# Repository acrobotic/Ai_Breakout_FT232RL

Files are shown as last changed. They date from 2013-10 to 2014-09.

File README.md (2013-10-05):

Overview
---
This repository includes the Eagle design files (schematics and layout) for our [FT232RL Brekout Board][1]. The FT232RL is a 
popular Integrated Circuit (IC) that provides a single-chip USB to asynchronous serial data (UART) transfer interface. This IC is
commonly known as the **FTDI chip** as it's manufactured by Future Technology Devices Internationa (FTDI).  

The FT232RL is extremely useful for sending data back and forth between a PC and a microcontroller (such as the ATMega328p 
that's used in the Arduino Uno R3). It can even be used to program a microcontroller whose boot section has been pre-loaded
with a bootloader (e.g., Optiboot).

For more info on how to use the FTDI and its use for data communication and microcontroller programming, please visit:
[http://learn.acrobotic.com/FTDI][2]

Product page
---
Please consider buying products from Acrobotic to help fund future Open-Source projects like this! We'll always put our best effort in every project, and release all our design files and code for you to use.

[Tutorials, technical details, and more information about this product can be found here: http://acrobotic.com/catalog/product/view/id/31][1]

License Information
---

All contents of this repository are licensed under a [Creative Commons Attribution-ShareAlike 3.0 Unported License](http://creativecommons.org/licenses/by-sa/3.0/).



[1]: http://acrobotic.com/catalog/product/view/id/31 "FT232RL Breakout Board"
[2]: http://learn.acrobotic.com/FTDI "Acrobotic FTDI Tutorial"

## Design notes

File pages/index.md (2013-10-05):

---
layout: page
title: Ai Breakout FT232RL
tagline: Board design files and example firmware for an FT232RL (FTDI) breakout board.
github_project: Ai_Breakout_FT232RL
github_user_url: https://github.com/acrobotic
---
{% include JB/setup %}
{% include INCLUDE.md %}

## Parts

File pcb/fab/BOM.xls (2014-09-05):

Ai Breakout FT232RL – BOM
Cisco Zabala (x1sc0@acrobotic.com) last updated: 05.09.2014
Manufacturer | Manuf. Part Number | Vendor | Vendor Part Number | Type | Designator | Qty | Description | Case | SMD, BGA, LCC, OR TH | Notes
Stackpole Electronics Inc | RMCF0603JT300R | Digi-Key | RMCF0603JT300RCT-ND | Resistors | R1 | 1 | RES 300 OHM 1/10W 5% 0603 | 0603 | SMD
Stackpole Electronics Inc | RMCF0603JT1K00 | Digi-Key | RMCF0603JT1K00CT-ND |  | R2 | 1 | RES 1K OHM 1/10W 5% 0603 | 0603 | SMD
Yageo | CC0603ZRY5V9BB104 | Digi-Key | 311-1343-1-ND | Capacitors | C1, C2 | 2 | CAP CER 0.1UF 50V Y5V 0603 | 0603 | SMD
Kemet | T491A106K010AT7280 | Digi-Key | 399-8268-1-ND |  | C3 | 1 | CAP TANT 10UF 10V 10% 1206 | EIA3216 | SMD
Yageo | CC0603ZRY5V7BB105 | Digi-Key | 311-1372-1-ND |  | C4 | 1 | CAP CER 1UF 16V Y5V 0603 | 0603 | SMD
OSRAM | LB Q39E-N1P1-35-1 | Digi-Key | 475-2815-1-ND | LEDs | ON | 1 | LED CHIPLED BLUE 470NM 0603 SMD | 0603 | SMD
OSRAM | LY Q976-P1S2-36 | Digi-Key | 475-2558-1-ND | IC | TXLED, RXLED | 2 | LED CHIPLED 587NM YLW 0603 SMD | 0603 | SMD
FTDI | FT232RL-REEL | Digi-Key | 768-1007-1-ND | ICs | IC1 | 1 | IC USB FS SERIAL UART 28-SSOP | 28-SSOP | SMD
 |  | Acrobotic | CON-00006 | Connectors | J1 | 1 | 0.1” Pitch, 6-Pin (Female, R/A) |  | TH
 |  | Acrobotic | CON-00002 | Connect. | JP1 | 1 | 0.1” Pitch, 8-Pin (Male) |  | TH | Easily cut to length
 |  | Acrobotic | CON-00014 |  | USB | 1 | CONN USB MICRO B RECPT SMT R/A |  | SMD
 |  | Acrobotic | CON-00008 | Connect. | - | 1 | 2-Pin Jumper |  | - | For power selection

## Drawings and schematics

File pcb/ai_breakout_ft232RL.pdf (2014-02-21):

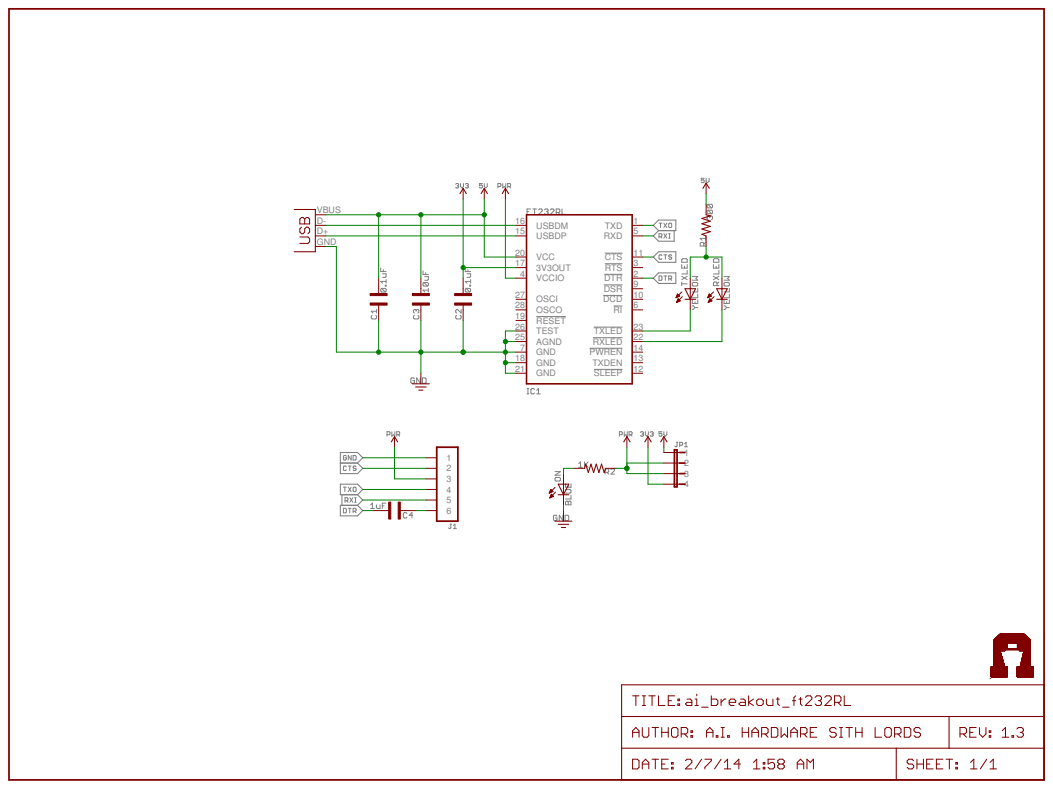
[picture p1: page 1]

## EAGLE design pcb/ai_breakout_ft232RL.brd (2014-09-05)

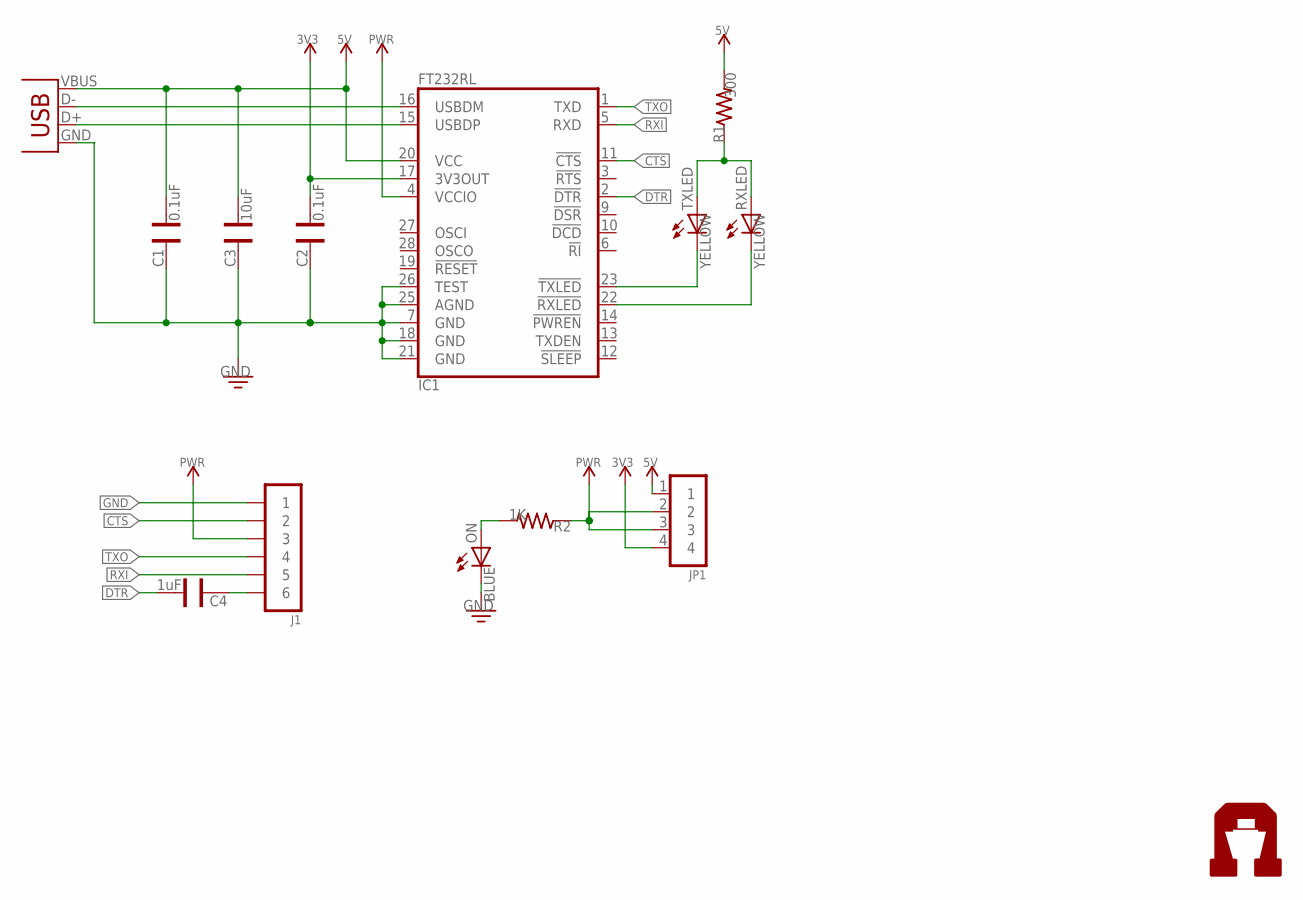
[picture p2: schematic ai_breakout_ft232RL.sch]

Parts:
C1, C2: 0.1uF; CAP-0603
C3: 10uF; CAP-0603
C4: 1uF; CAP-0603
IC1: FT2332RL; SSOP28-LD
J1: 1X06LONG; 1X06-LONG
JP1: 1X04NOSILK; 1X04-NOSILK
ON: BLUE; LED-0603
R1: 300; RES-0603
R2: 1K; RES-0603
RXLED: YELLOW; LED-0603
TXLED: YELLOW; LED-0603
U$3: AI-LOGOL; AI-LOGO-L
USB1: USBMICROB-TH; USB-MICROB-TH

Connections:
3V3: C2.1, IC1.17 (3V3OUT), JP1.4
5V: C1.1, C3.1, IC1.20 (VCC), JP1.1, R1.2, USB1.VBUS
CTS: IC1.11 (!CTS), J1.2
DTR: C4.1, IC1.2 (!DTR)
GND: C1.2, C2.2, C3.2, IC1.7 (GND), IC1.18 (GND), IC1.21 (GND), IC1.25 (AGND), IC1.26 (TEST), J1.1, ON.C, USB1.GND
unnamed: IC1.23 (!TXLED), TXLED.C
unnamed: IC1.22 (!RXLED), RXLED.C
unnamed: IC1.16 (USBDM), USB1.D-
unnamed: IC1.15 (USBDP), USB1.D+
unnamed: ON.A, R2.2
unnamed: R1.1, RXLED.A, TXLED.A
unnamed: C4.2, J1.6
PWR: IC1.4 (VCCIO), J1.3, JP1.2, JP1.3, R2.1
RXI: IC1.5 (RXD), J1.5
TXO: IC1.1 (TXD), J1.4

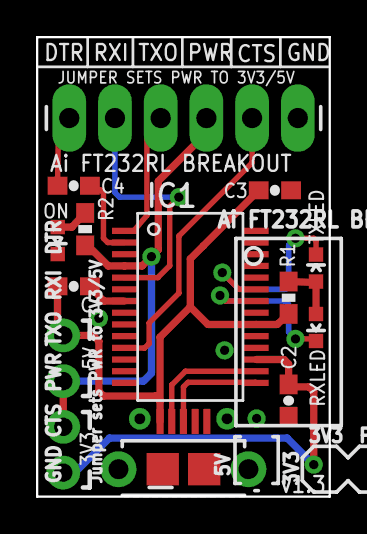
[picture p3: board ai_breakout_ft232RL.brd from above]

Board: 2 copper layers, 16.3 x 25.5 mm, 14 parts (1 on the bottom side), 15 nets.

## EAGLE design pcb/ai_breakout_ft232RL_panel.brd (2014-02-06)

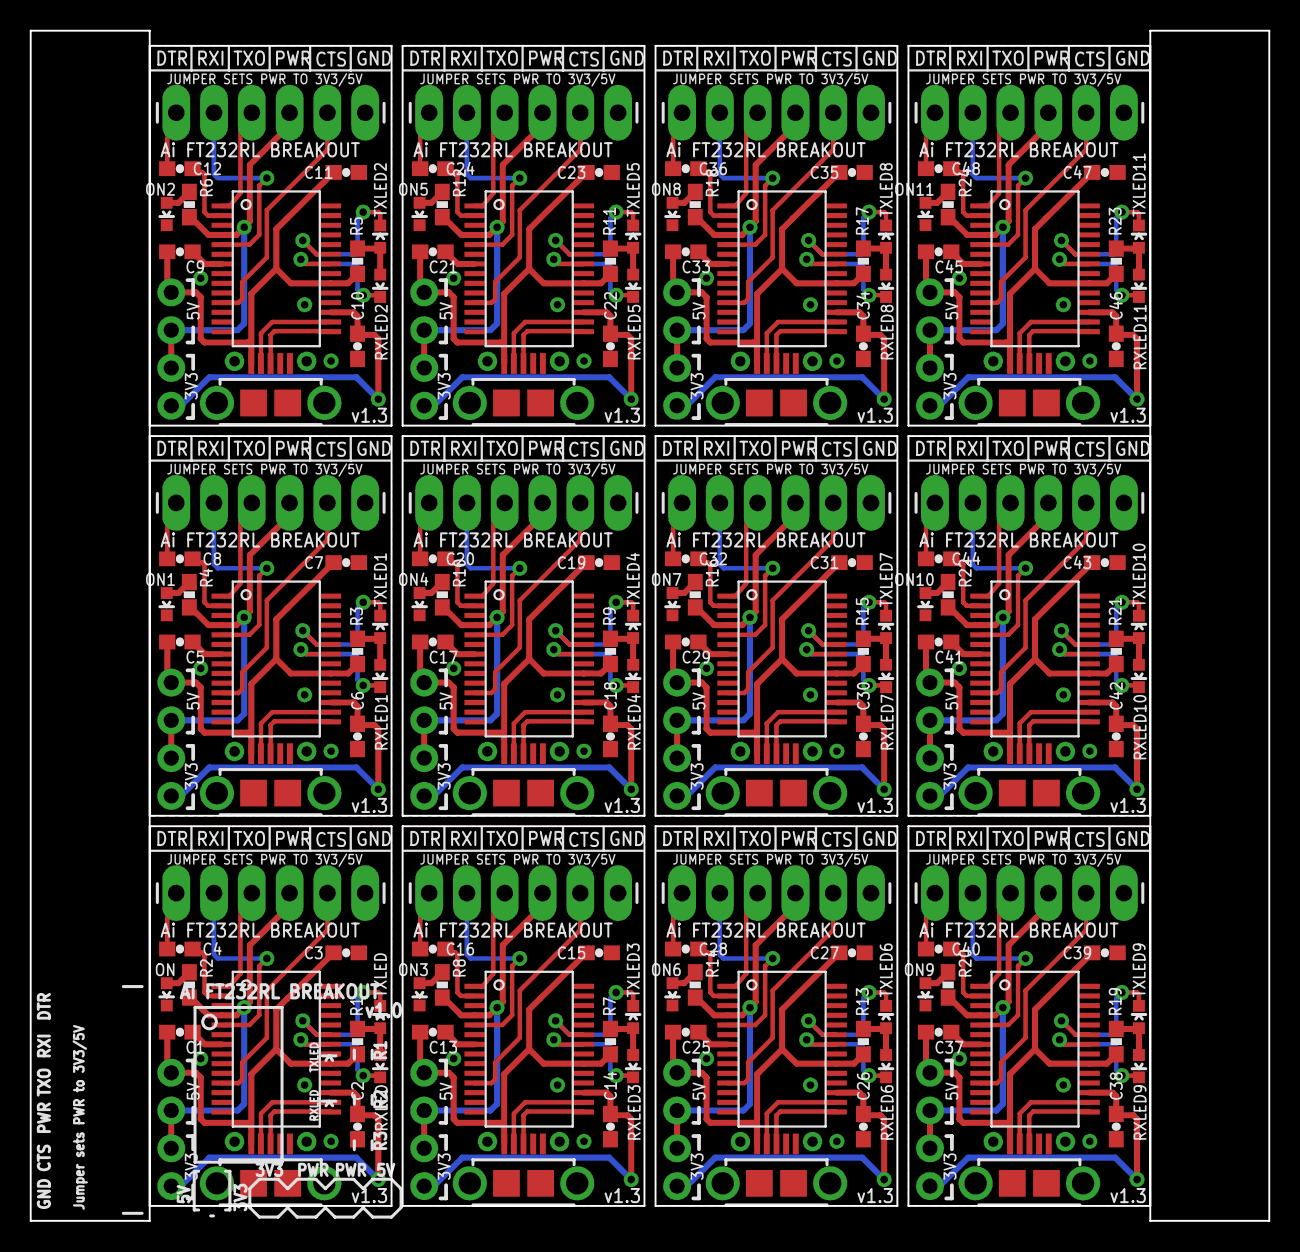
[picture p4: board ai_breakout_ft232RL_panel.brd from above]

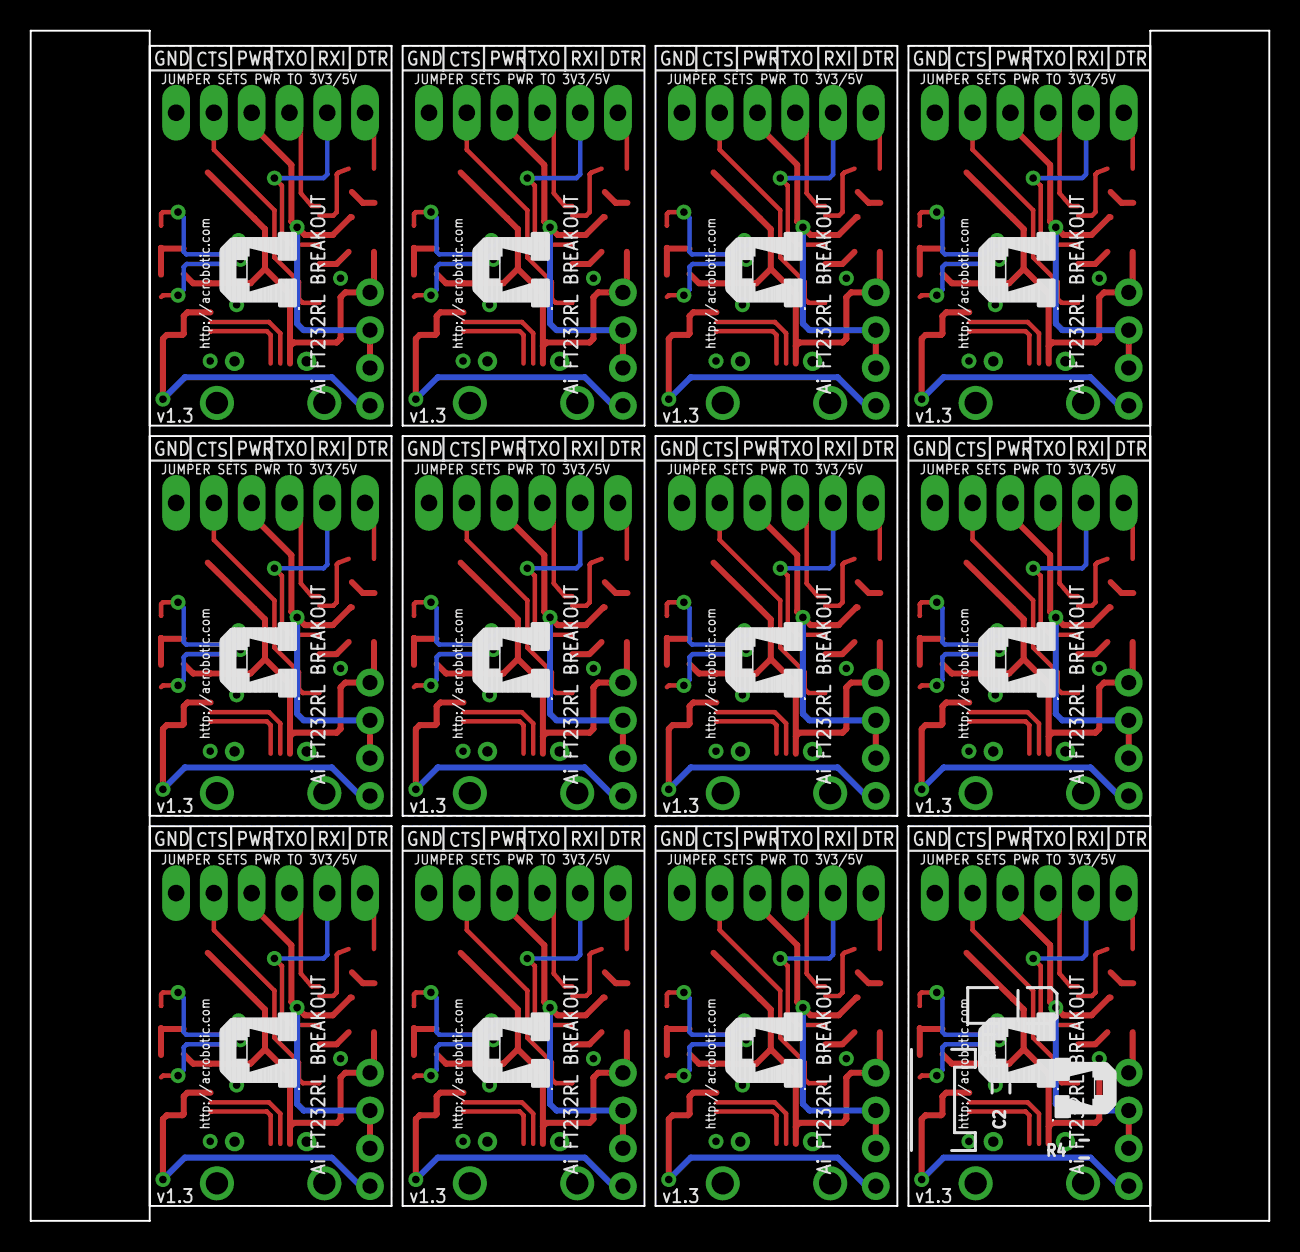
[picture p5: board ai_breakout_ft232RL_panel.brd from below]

Board: 2 copper layers, 83.3 x 80.0 mm, 168 parts (12 on the bottom side), 180 nets.

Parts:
C1, C2, C5, C6, C9, C10, C13, C14, C17, C18, C21, C22, C25, C26, C29, C30, C33, C34, C37, C38, C41, C42, C45, C46: 0.1uF; CAP-0603
C3, C7, C11, C15, C19, C23, C27, C31, C35, C39, C43, C47: 10uF; CAP-0603
C4, C8, C12, C16, C20, C24, C28, C32, C36, C40, C44, C48: 1uF; CAP-0603
IC1, IC2, IC3, IC4, IC5, IC6, IC7, IC8, IC9, IC10, IC11, IC12: FT2332RL; SSOP28-LD
J1, J2, J3, J4, J5, J6, J7, J8, J9, J10, J11, J12: 1X06LONG; 1X06-LONG
JP1, JP2, JP3, JP4, JP5, JP6, JP7, JP8, JP9, JP10, JP11, JP12: 1X04NOSILK; 1X04-NOSILK
ON, ON1, ON2, ON3, ON4, ON5, ON6, ON7, ON8, ON9, ON10, ON11: BLUE; LED-0603
R1, R3, R5, R7, R9, R11, R13, R15, R17, R19, R21, R23: 300; RES-0603
R2, R4, R6, R8, R10, R12, R14, R16, R18, R20, R22, R24: 1K; RES-0603
RXLED, RXLED1, RXLED2, RXLED3, RXLED4, RXLED5, RXLED6, RXLED7, RXLED8, RXLED9, RXLED10, RXLED11: YELLOW; LED-0603
TXLED, TXLED1, TXLED2, TXLED3, TXLED4, TXLED5, TXLED6, TXLED7, TXLED8, TXLED9, TXLED10, TXLED11: YELLOW; LED-0603
U$1, U$2, U$3, U$4, U$5, U$6, U$7, U$8, U$9, U$10, U$11, U$12: AI-LOGOL; AI-LOGO-L
USB1, USB2, USB3, USB4, USB5, USB6, USB7, USB8, USB9, USB10, USB11, USB12: USBMICROB-TH; USB-MICROB-TH

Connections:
3V1: C6.1, IC2.17, JP2.4
3V2: C10.1, IC3.17, JP3.4
3V3: C2.1, IC1.17, JP1.4
3V4: C14.1, IC4.17, JP4.4
3V5: C18.1, IC5.17, JP5.4
3V6: C22.1, IC6.17, JP6.4
3V7: C26.1, IC7.17, JP7.4
3V8: C30.1, IC8.17, JP8.4
3V9: C34.1, IC9.17, JP9.4
3V10: C38.1, IC10.17, JP10.4
3V11: C42.1, IC11.17, JP11.4
3V12: C46.1, IC12.17, JP12.4
5V: C1.1, C3.1, IC1.20, JP1.1, R1.2, USB1.VBUS
5V1: C5.1, C7.1, IC2.20, JP2.1, R3.2, USB2.VBUS
5V2: C9.1, C11.1, IC3.20, JP3.1, R5.2, USB3.VBUS
5V3: C13.1, C15.1, IC4.20, JP4.1, R7.2, USB4.VBUS
5V4: C17.1, C19.1, IC5.20, JP5.1, R9.2, USB5.VBUS
5V5: C21.1, C23.1, IC6.20, JP6.1, R11.2, USB6.VBUS
5V6: C25.1, C27.1, IC7.20, JP7.1, R13.2, USB7.VBUS
5V7: C29.1, C31.1, IC8.20, JP8.1, R15.2, USB8.VBUS
5V8: C33.1, C35.1, IC9.20, JP9.1, R17.2, USB9.VBUS
5V9: C37.1, C39.1, IC10.20, JP10.1, R19.2, USB10.VBUS
5V10: C41.1, C43.1, IC11.20, JP11.1, R21.2, USB11.VBUS
5V11: C45.1, C47.1, IC12.20, JP12.1, R23.2, USB12.VBUS
CTS: IC1.11, J1.2
CTS1: IC2.11, J2.2
CTS2: IC3.11, J3.2
CTS3: IC4.11, J4.2
CTS4: IC5.11, J5.2
CTS5: IC6.11, J6.2
CTS6: IC7.11, J7.2
CTS7: IC8.11, J8.2
CTS8: IC9.11, J9.2
CTS9: IC10.11, J10.2
CTS10: IC11.11, J11.2
CTS11: IC12.11, J12.2
DTR: C4.1, IC1.2
DTR1: C8.1, IC2.2
DTR2: C12.1, IC3.2
DTR3: C16.1, IC4.2
DTR4: C20.1, IC5.2
DTR5: C24.1, IC6.2
DTR6: C28.1, IC7.2
DTR7: C32.1, IC8.2
DTR8: C36.1, IC9.2
DTR9: C40.1, IC10.2
DTR10: C44.1, IC11.2
DTR11: C48.1, IC12.2
GND: C1.2, C2.2, C3.2, IC1.7, IC1.18, IC1.21, IC1.25, IC1.26, J1.1, ON.C, USB1.GND
GND1: C5.2, C6.2, C7.2, IC2.7, IC2.18, IC2.21, IC2.25, IC2.26, J2.1, ON1.C, USB2.GND
GND2: C9.2, C10.2, C11.2, IC3.7, IC3.18, IC3.21, IC3.25, IC3.26, J3.1, ON2.C, USB3.GND
GND3: C13.2, C14.2, C15.2, IC4.7, IC4.18, IC4.21, IC4.25, IC4.26, J4.1, ON3.C, USB4.GND
GND4: C17.2, C18.2, C19.2, IC5.7, IC5.18, IC5.21, IC5.25, IC5.26, J5.1, ON4.C, USB5.GND
GND5: C21.2, C22.2, C23.2, IC6.7, IC6.18, IC6.21, IC6.25, IC6.26, J6.1, ON5.C, USB6.GND
GND6: C25.2, C26.2, C27.2, IC7.7, IC7.18, IC7.21, IC7.25, IC7.26, J7.1, ON6.C, USB7.GND
GND7: C29.2, C30.2, C31.2, IC8.7, IC8.18, IC8.21, IC8.25, IC8.26, J8.1, ON7.C, USB8.GND
GND8: C33.2, C34.2, C35.2, IC9.7, IC9.18, IC9.21, IC9.25, IC9.26, J9.1, ON8.C, USB9.GND
GND9: C37.2, C38.2, C39.2, IC10.7, IC10.18, IC10.21, IC10.25, IC10.26, J10.1, ON9.C, USB10.GND
GND10: C41.2, C42.2, C43.2, IC11.7, IC11.18, IC11.21, IC11.25, IC11.26, J11.1, ON10.C, USB11.GND
GND11: C45.2, C46.2, C47.2, IC12.7, IC12.18, IC12.21, IC12.25, IC12.26, J12.1, ON11.C, USB12.GND
unnamed: IC1.23, TXLED.C
unnamed: IC1.22, RXLED.C
unnamed: IC1.16, USB1.D-
unnamed: IC1.15, USB1.D+
unnamed: ON.A, R2.2
unnamed: R1.1, RXLED.A, TXLED.A
unnamed: C4.2, J1.6
unnamed: IC2.16, USB2.D-
unnamed: IC2.15, USB2.D+
unnamed: R3.1, RXLED1.A, TXLED1.A
unnamed: ON1.A, R4.2
unnamed: IC2.23, TXLED1.C
unnamed: IC2.22, RXLED1.C
unnamed: C8.2, J2.6
unnamed: IC3.16, USB3.D-
unnamed: IC3.15, USB3.D+
unnamed: R5.1, RXLED2.A, TXLED2.A
unnamed: ON2.A, R6.2
unnamed: IC3.23, TXLED2.C
unnamed: IC3.22, RXLED2.C
unnamed: C12.2, J3.6
unnamed: IC4.16, USB4.D-
unnamed: IC4.15, USB4.D+
unnamed: R7.1, RXLED3.A, TXLED3.A
unnamed: ON3.A, R8.2
unnamed: IC4.23, TXLED3.C
unnamed: IC4.22, RXLED3.C
unnamed: C16.2, J4.6
unnamed: IC5.16, USB5.D-
unnamed: IC5.15, USB5.D+
unnamed: R9.1, RXLED4.A, TXLED4.A
unnamed: ON4.A, R10.2
unnamed: IC5.23, TXLED4.C
unnamed: IC5.22, RXLED4.C
unnamed: C20.2, J5.6
unnamed: IC6.16, USB6.D-
unnamed: IC6.15, USB6.D+
unnamed: R11.1, RXLED5.A, TXLED5.A
unnamed: ON5.A, R12.2
unnamed: IC6.23, TXLED5.C
unnamed: IC6.22, RXLED5.C
unnamed: C24.2, J6.6
unnamed: IC7.16, USB7.D-
unnamed: IC7.15, USB7.D+
unnamed: R13.1, RXLED6.A, TXLED6.A
unnamed: ON6.A, R14.2
unnamed: IC7.23, TXLED6.C
unnamed: IC7.22, RXLED6.C
unnamed: C28.2, J7.6
unnamed: IC8.16, USB8.D-
unnamed: IC8.15, USB8.D+
unnamed: R15.1, RXLED7.A, TXLED7.A
unnamed: ON7.A, R16.2
unnamed: IC8.23, TXLED7.C
unnamed: IC8.22, RXLED7.C
unnamed: C32.2, J8.6
unnamed: IC9.16, USB9.D-
unnamed: IC9.15, USB9.D+
unnamed: R17.1, RXLED8.A, TXLED8.A
unnamed: ON8.A, R18.2
unnamed: IC9.23, TXLED8.C
unnamed: IC9.22, RXLED8.C
unnamed: C36.2, J9.6
unnamed: IC10.16, USB10.D-
unnamed: IC10.15, USB10.D+
unnamed: R19.1, RXLED9.A, TXLED9.A
unnamed: ON9.A, R20.2
unnamed: IC10.23, TXLED9.C
unnamed: IC10.22, RXLED9.C
unnamed: C40.2, J10.6
unnamed: IC11.16, USB11.D-
unnamed: IC11.15, USB11.D+
unnamed: R21.1, RXLED10.A, TXLED10.A
unnamed: ON10.A, R22.2
unnamed: IC11.23, TXLED10.C
unnamed: IC11.22, RXLED10.C
unnamed: C44.2, J11.6
unnamed: IC12.16, USB12.D-
unnamed: IC12.15, USB12.D+
unnamed: R23.1, RXLED11.A, TXLED11.A
unnamed: ON11.A, R24.2
unnamed: IC12.23, TXLED11.C
unnamed: IC12.22, RXLED11.C
unnamed: C48.2, J12.6
PWR: IC1.4, J1.3, JP1.2, JP1.3, R2.1
PWR1: IC2.4, J2.3, JP2.2, JP2.3, R4.1
PWR2: IC3.4, J3.3, JP3.2, JP3.3, R6.1
PWR3: IC4.4, J4.3, JP4.2, JP4.3, R8.1
PWR4: IC5.4, J5.3, JP5.2, JP5.3, R10.1
PWR5: IC6.4, J6.3, JP6.2, JP6.3, R12.1
PWR6: IC7.4, J7.3, JP7.2, JP7.3, R14.1
PWR7: IC8.4, J8.3, JP8.2, JP8.3, R16.1
PWR8: IC9.4, J9.3, JP9.2, JP9.3, R18.1
PWR9: IC10.4, J10.3, JP10.2, JP10.3, R20.1
PWR10: IC11.4, J11.3, JP11.2, JP11.3, R22.1
PWR11: IC12.4, J12.3, JP12.2, JP12.3, R24.1
RXI: IC1.5, J1.5
RXI1: IC2.5, J2.5
RXI2: IC3.5, J3.5
RXI3: IC4.5, J4.5
RXI4: IC5.5, J5.5
RXI5: IC6.5, J6.5
RXI6: IC7.5, J7.5
RXI7: IC8.5, J8.5
RXI8: IC9.5, J9.5
RXI9: IC10.5, J10.5
RXI10: IC11.5, J11.5
RXI11: IC12.5, J12.5
TXO: IC1.1, J1.4
TXO1: IC2.1, J2.4
TXO2: IC3.1, J3.4
TXO3: IC4.1, J4.4
TXO4: IC5.1, J5.4
TXO5: IC6.1, J6.4
TXO6: IC7.1, J7.4
TXO7: IC8.1, J8.4
TXO8: IC9.1, J9.4
TXO9: IC10.1, J10.4
TXO10: IC11.1, J11.4
TXO11: IC12.1, J12.4

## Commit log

2013-07-17 first commit.
    [BOM.xls, ai_ft232_breakout.sch]
2013-07-18 version 1.0 of the design files.
    [Ai_FT232_Breakout.brd, Ai_FT232_Breakout.sch, ai_ft232rl_breakout.brd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]
2013-07-18 removing unwanted files.
    [Ai_FT232_Breakout.brd, Ai_FT232_Breakout.sch]
2013-07-18 changed the size of the board's png.
2013-07-18 aligned board to origin.
    [ai_ft232rl_breakout.brd]
2013-07-22 re-routed manually, and changed components to use the Ai Eagle libraries.
    [ai_ft232rl_breakout.brd, ai_ft232rl_breakout.sch]
2013-07-25 changed pcb edge width
    [ai_ft232rl_breakout.brd]
2013-07-25 renaming files.
    [ai_breakout_ft2323RL.brd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]
2013-07-25 deleting old (renamed) files.
    [ai_ft232rl_breakout.brd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]
2013-07-26 Small fixup in schematic
    [ai_breakout_ft2323RL.sch]
2013-10-05 Revision 1.1
    [ai_breakout_ft2323RL.brd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]
2013-10-05 Finalized BOM
    [BOM.xls, ai_breakout_ft2323RL.brd, ai_breakout_ft2323RL.sch]
2013-10-05 Fixed silkscreen typo
    [ai_breakout_ft2323RL.brd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]
2013-10-11 Small changes in trace sizes, and silkscreen
    [ai_breakout_ft2323RL.brd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]
2013-10-11 updating pdf file for schematic
2013-10-15 minor change on gerbers
2013-11-21 New revision and adding panelized version
    [ai_breakout_ft2323RL_panel.brd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]
2013-11-22 Updated BOM
    [BOM.xls, ai_breakout_ft2323RL_panel.brd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]
2013-12-15 fixed typo in filenames
    [ai_breakout_ft232rl.brd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]
2014-02-06 updated the micro-b connector and designed a new panelized version
    [BOM.xls, ai_breakout_ft2323RL.brd, ai_breakout_ft2323RL.sch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]
2014-02-07 deleting old files named using lowercase rl
    [ai_breakout_ft232rl.brd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]
2014-02-07 deleting old files named using 2323 instead of 232
    [ai_breakout_ft232RL.brd, ai_breakout_ft232RL.sch, ai_breakout_ft232RL_panel.brd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]
2014-02-07 deleting old files named using RL instead of rl
    [ai_breakout_ft2323rl_panel.gbl, ai_breakout_ft2323rl_panel.gbo, ai_breakout_ft2323rl_panel.gbs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]
2014-09-05 updating libraries
    [ai_breakout_ft232RL.brd, ai_breakout_ft232RL.sch]
2014-09-05 small update to BOM
    [BOM.xls]
